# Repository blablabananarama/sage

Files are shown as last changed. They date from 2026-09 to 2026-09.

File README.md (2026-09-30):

# Bayleaf: ultra-low-profile wireless split keyboard (reproduction)

This is an open, buildable re-creation of Sebastian Graz's [Bayleaf](https://www.graz.io/articles/bayleaf-wireless-keyboard/): a 60-key (2 × 5×6) ortholinear split keyboard. It uses Kailh PG1316S laptop-style switches, runs ZMK on nice!nano controllers, and sits in a CNC-machined aluminium case 5 mm thick.

> **Provenance.** The original Bayleaf is a one-off prototype and is **not open source**. None of its files are used here. This repository is an independent design built to the published specs (139 × 93 mm per half, 5 mm thick, ~180 g, PG1316S, nice!nano/ZMK, CNC aluminium enclosure, MJF keycaps). Everything else was designed from scratch: board layout, pin mapping, case geometry, keymap and part choices. The PG1316S land pattern comes from Kailh's datasheet (CPG1316S01D02).

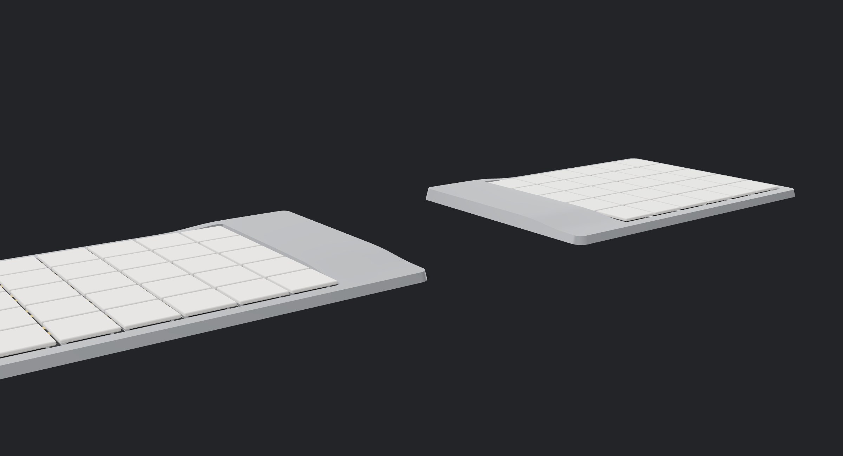
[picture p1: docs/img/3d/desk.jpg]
Bayleaf reproduction on a desk mat


| | |
|---|---|
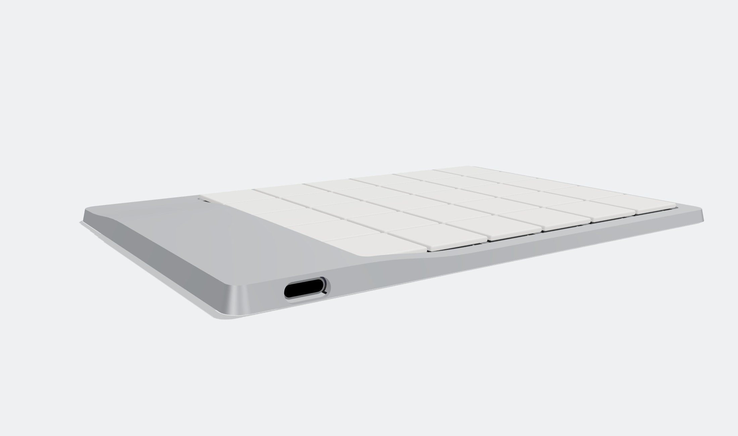
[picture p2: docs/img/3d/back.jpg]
back: USB-C in the S-bend below the plateau
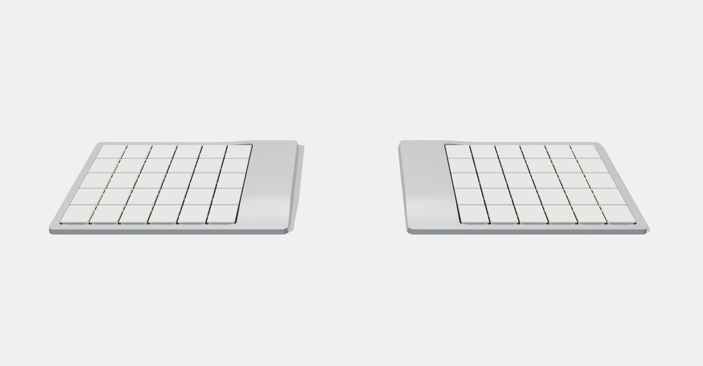
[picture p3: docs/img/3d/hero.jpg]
both halves
|  |  |
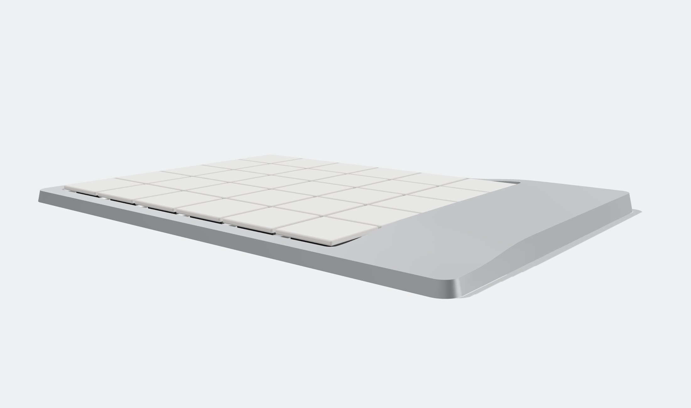
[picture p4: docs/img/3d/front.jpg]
front: the rim rising into the plateau
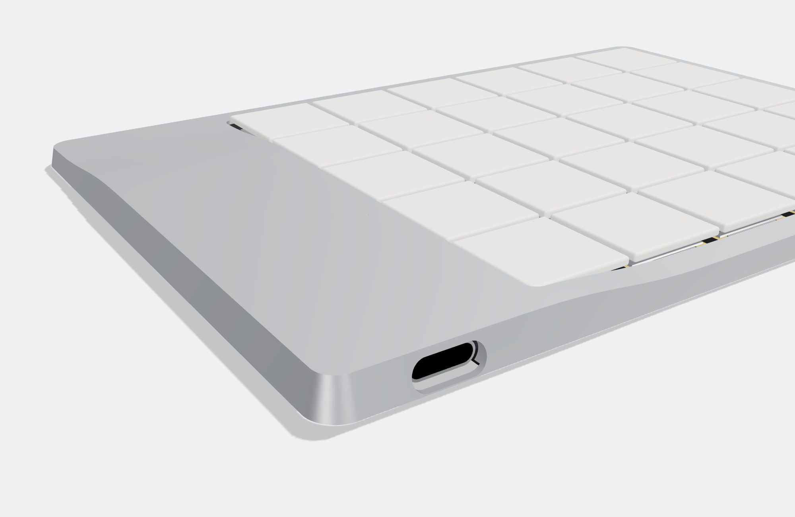
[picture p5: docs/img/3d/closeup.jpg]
controller corner: plateau and bends
|  |  |
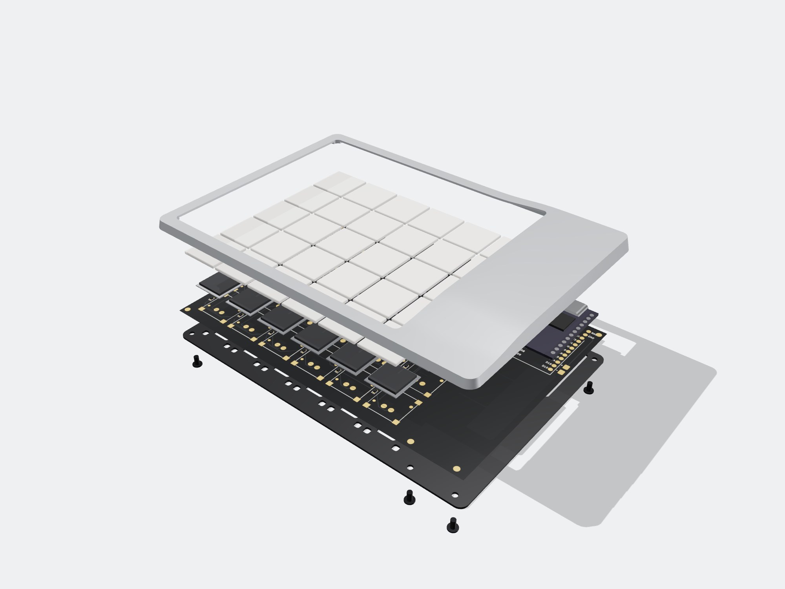
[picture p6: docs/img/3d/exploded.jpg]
exploded: shell, keycaps, switches, PCB, bottom plate, screws
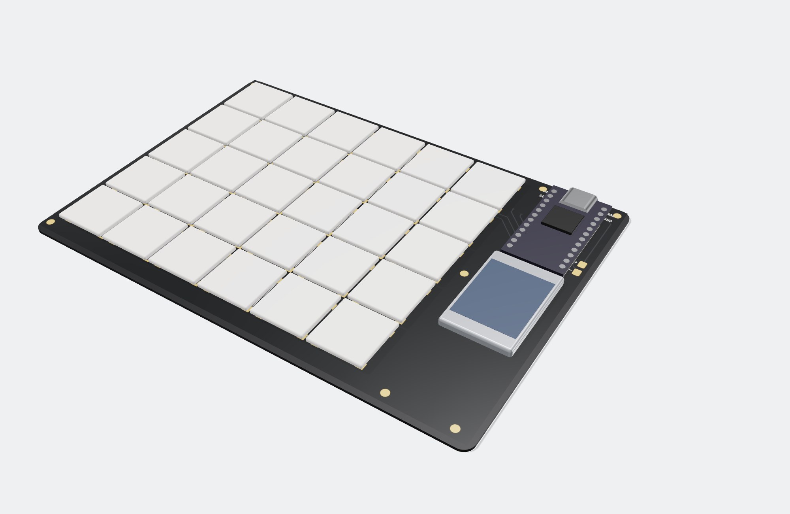
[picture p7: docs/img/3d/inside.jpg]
inside: PCB with the nice!nano, battery and switches
|  |  |
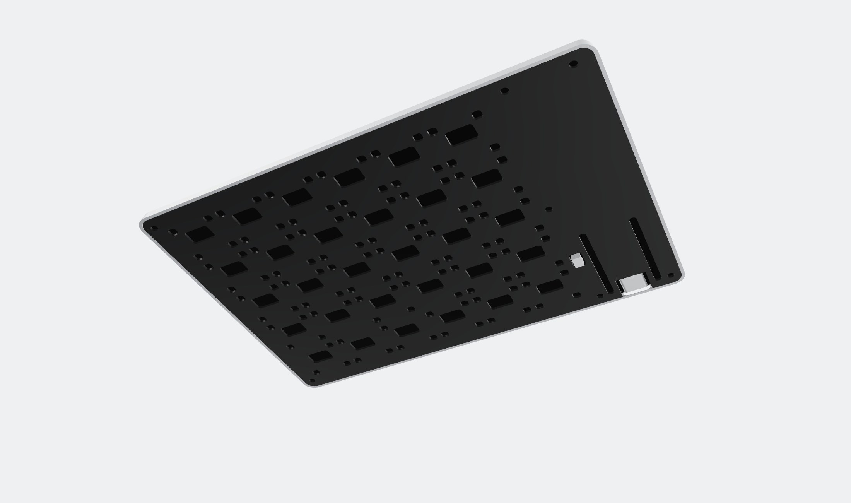
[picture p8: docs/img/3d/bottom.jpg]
underside: black FR4 bottom plate with its windows and the reset button
|  | |
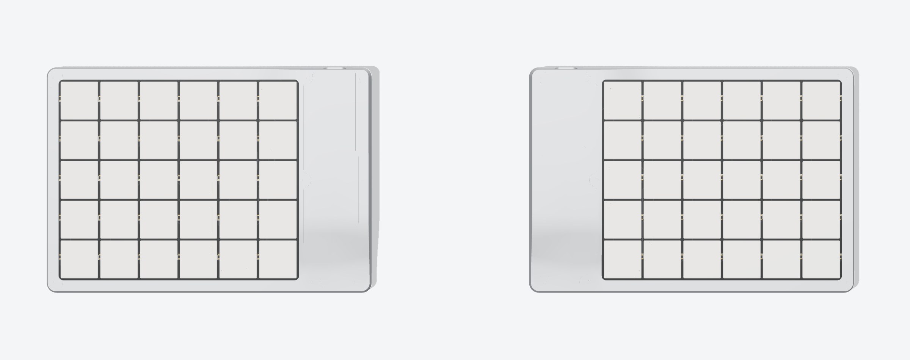
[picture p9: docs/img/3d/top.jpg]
top view
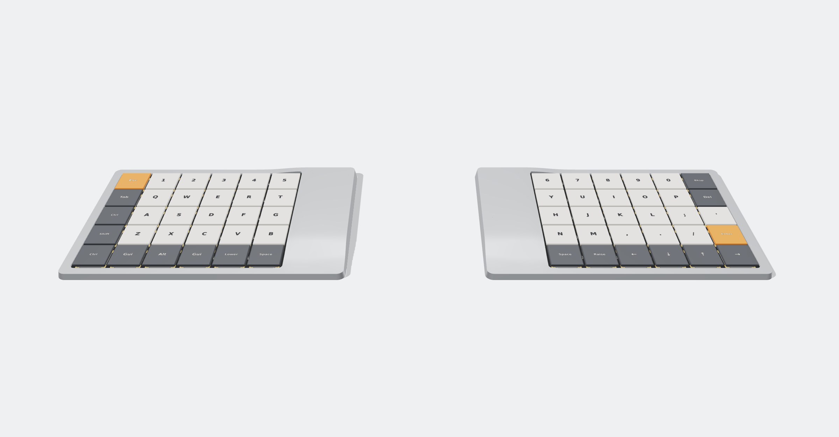
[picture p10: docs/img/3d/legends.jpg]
with the default keymap as legends
|  |  |

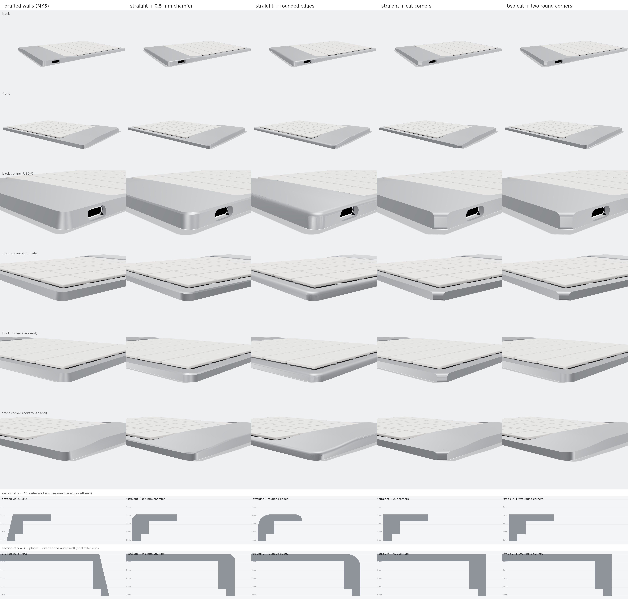
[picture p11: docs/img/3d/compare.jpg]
case variants side by side: drafted walls, straight + chamfer, straight + rounded edges, straight + cut corners


**[Interactive case viewer](https://claude.ai/artifact/CuZ9wQ9LTKb2B2hHYhkEA2)**: rotate the five case versions, switch between them and try finishes (source: `docs/viewer/index.html`).

*Renders are generated from the actual STEP files and the routed PCB artwork (`docs/render3d/render.sh`). The case follows the original's MK5 drawing for the plan view and, for the top surface, the shape drawn in the [case sketchpad](https://claude.ai/artifact/11zAxZXfv3bXQXGKN8ovCU) ([data](docs/case-sketchpad-shape.json)): a one-piece silver shell with two flat levels, a 3.2 mm rim around the keys and a 5.0 mm plateau over the controller, joined by soft S-bends, plus a screwed-on black FR4 bottom plate.*

| | Original Bayleaf (published) | This reproduction |
|---|---|---|
| Layout | 60 % ortholinear split | 2 × 5 rows × 6 columns, 17 × 17 mm pitch |
| Size per half | 139 × 93 mm; "tallest part is only 5 mm" | 139.4 × 96.8 mm base. 3.2 mm rim around the keys; 5.0 mm plateau over the controller |
| Weight | 180 g | ~165 g estimated (15 g aluminium shell + 17 g FR4 plate per half) |
| Switches | Kailh PG1316S | Kailh PG1316S, soldered from below with an iron: contacts through castellated half-holes, frame anchors through plated holes (a hotplate is optional) |
| Keycaps | custom MJF prints | stock Kailh PG1316S 1U caps (16 × 16 mm) |
| Controller | nice!nano, ZMK | nice!nano v2 soldered flush, ZMK (BLE split) |
| Battery | "over a month" | 302030 LiPo (~120–150 mAh) per half, deep sleep after 15 min |
| Case | CNC aluminium, raised over the controller | One-piece CNC 6061 shell (key window, roofed controller bay, 7 tapped M2 posts) + 0.8 mm FR4 bottom plate (a copper-free PCB, so the radio gets out) ([notes](docs/case-drawing.md)) |

## What's in here

```
hardware/pcb/generate_pcb.py      the whole PCB as code: placement, nets, outline -> Freerouting -> DRC -> fab files;
                                  also the FR4 bottom plates
hardware/pcb/bayleaf-{left,right}.kicad_pcb   routed KiCad 7 boards (open in KiCad to inspect or edit)
hardware/pcb/lib/bayleaf.pretty/  footprints: PG1316S (castellated, hand-solderable), nice!nano (flush), battery pads
hardware/pcb/fab/{left,right}/    gerbers+drill zip, JLCPCB BOM/CPL, 3D STEP of the board, DRC report
hardware/pcb/fab/plate-{left,right}/  gerbers+drill zip of the FR4 bottom plates
hardware/case/case.py             parametric shell (drafted or straight + chamfer) (CadQuery); out/ has STEP + STL (plate too, for reference)
firmware/                         ZMK shield "bayleaf" + keymap; built by .github/workflows/firmware.yml
docs/BOM.csv                      full bill of materials with prices
docs/ordering.md                  exact fab settings (PCB, PCBA, CNC, parts)
docs/shopping-list.md             every part to buy, with shop links
docs/assembly.md                  step-by-step build guide
docs/schematic.md                 circuit / pin map
docs/case-drawing.md              case dimensions, tapped holes, screws
```

| Left PCB | Right PCB |
|---|---|
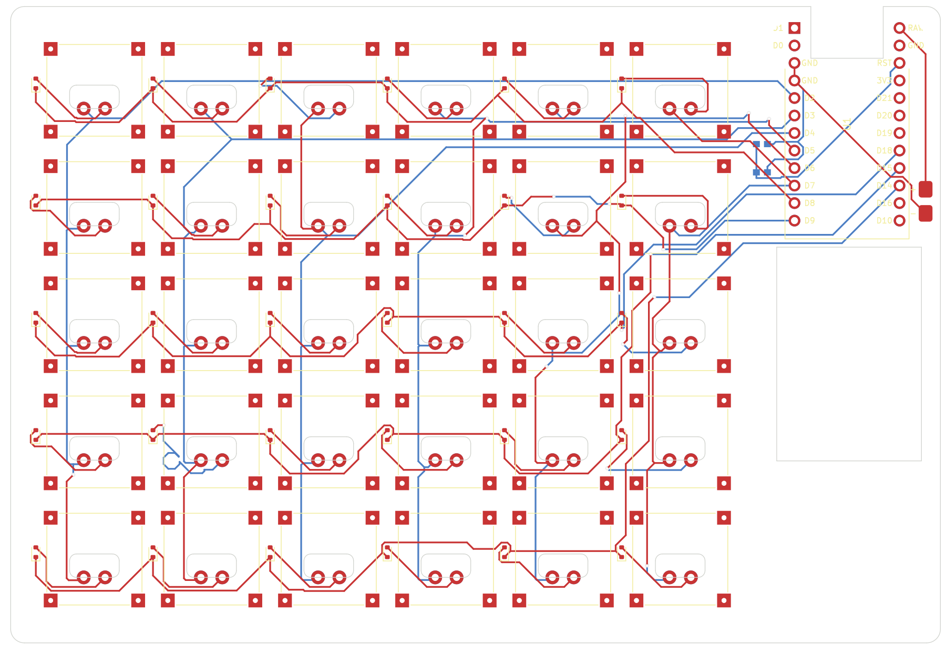
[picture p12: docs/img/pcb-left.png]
left pcb
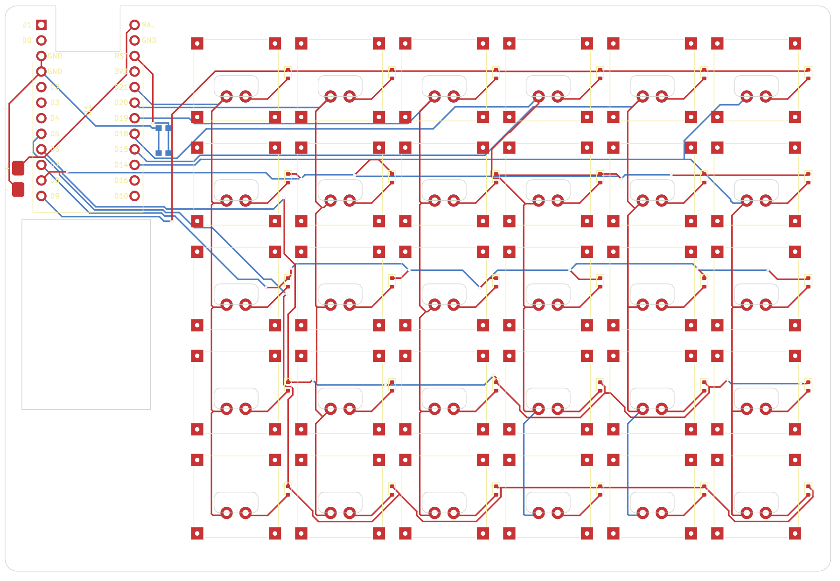
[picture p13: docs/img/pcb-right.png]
right pcb
|  |  |

## How much does one cost?

These are estimates from September 2026 for a single keyboard, including spares and shipping. The details are in [`docs/BOM.csv`](docs/BOM.csv).

| | USD |
|---|---:|
| PCBs (2 designs × 5 pcs, 0.8 mm, ENIG, castellated holes) | 60 |
| FR4 bottom plates (2 designs × 5 pcs, no copper) | 16 |
| 64 × Kailh PG1316S switches | 64 |
| 60 × PG1316S keycaps | 27 |
| 2 × nice!nano v2 | 50 |
| 2 × LiPo 302030 | 8 |
| Diodes, reset buttons | 2 |
| Foam tape, Kapton tape, bumpons, M2 screws | 17 |
| Shipping (rough) | 35 |
| 2 × CNC aluminium shell (6061, anodised) | 170 |
| **Electronics only** (PCBs, switches, diodes, controllers, batteries, reset buttons) | **≈ $184** |
| **Total with aluminium case** | **≈ $449** |
| **Total with printed nylon case instead** | **≈ $309** |

Optional extras: JLCPCB assembly of the 60 diodes (≈ $35), SMT stencils (≈ $14), and low-temp paste; a small hotplate is optional (≈ $30–120).

Most of the extra units are leftovers you can't avoid: 3 spare PCBs per side at the 5-piece minimum, spare switches, and so on.

## Build it

1. **Order**: follow [docs/ordering.md](docs/ordering.md). Upload the gerber zips, optionally the JLC BOM/CPL, and the case STEP files. Buy switches, caps, 2 nice!nanos and 2 cells.
2. **Firmware**: GitHub Actions builds `bayleaf_left`, `bayleaf_right` and `settings_reset` UF2s on every push. See [firmware/README.md](firmware/README.md).
3. **Assemble**: follow [docs/assembly.md](docs/assembly.md). The rough order is diodes → switches (iron from below: frame anchors, then contacts) → reset button (underside) → nice!nano flush → battery → PCB into the shell → bottom plate + 7 screws.

## Regenerating the design

The committed outputs are all you need to order. To change something (pitch, board size, pin map, case wall), edit the constants at the top of `generate_pcb.py` or `case.py` and run:

```sh
make pcb      # KiCad 7 python (pcbnew) + Freerouting 2.x jar (FREEROUTING_JAR=...)
make case     # CadQuery (shell; imports the FR4 plate for the renders)
make render   # README renders (docs/render3d)
```

The PCB script autoroutes with Freerouting and re-runs until nothing is unrouted. It writes a DRC report next to the gerbers. The committed boards have **0 unconnected pads and 0 electrical DRC errors**; the report only lists cosmetic silkscreen and library-path warnings. The bottom plates are generated in the same run. Freerouting isn't deterministic, so each regeneration produces different (equally valid) traces.

## Status and caveats

* **Not yet built.** The design passes DRC and the case was checked against the board in CAD, but no physical prototype exists yet. Order one set of PCBs before ordering in quantity.
* **Hand-solderable switches.** The PG1316S footprint uses the trick from Mike Holscher's working [mikecinq](https://github.com/mikeholscher/zmk-config-mikecinq): a window in the board under each switch, with the two contacts on plated half-holes at its edge, soldered from below with an iron. On top of that, each of the four frame-anchor pads has a plated hole with a bottom pad, so the anchors can be soldered from below too and no hotplate is needed. The anchor holes are **my addition and untested**: solder one switch first and check it holds before doing the rest. The hotplate route still works on the same board. The footprint is drawn independently from the Kailh land pattern, using his proven contact positions. Order the PCB with *castellated holes*, and print it 1:1 to check against a real switch first.
* The nice!nano is soldered flush, without sockets, to reach 5 mm. Flash and test it **before** soldering it down.
* The LCSC part numbers in the BOM are well-known parts, but check stock before ordering.
* **Case vs. the original.** The plan view comes from the MK5 drawing and the top surface from the sketchpad shape (3.2 / 5.0 mm levels, a square-cornered plateau at x ≥ 96.5, y ≤ 76 mm, 16.5 mm S-bends). The overall depth (4.2 mm border all round) and the keycap height (~4.4 mm) are my estimates. [docs/case-drawing.md](docs/case-drawing.md) marks which numbers come from where.
  * The plateau only covers the back 76 mm of the controller strip, so the PCB is laid out for it: the nice!nano's USB-C faces the **back** wall, the reset button (KMR2) sits beside it, and the cell is a **302030** in front of it (a 302040 would run into the bend).
  * The two posts beside the USB port are moved outward, so they don't land on the nice!nano's pins.
  * Threads are 2 mm deep under the plateau and 1.1 mm under the rim (M2×2 screws there); the drawing's 3 mm ones don't fit under 5 mm.
  * **No power switch.** The cell is wired straight to the nice!nano; ZMK's deep sleep (after 15 min idle, a key press wakes it) keeps the drain to a few µA. To store it for months, unsolder a battery lead.
  * The USB-C opening is a stadium around the receptacle (9.7 × 3.9 mm). The receptacle sits 1.5–2 mm behind the outer wall, so the cable's plug overmold has to fit that opening: slim-overmold cables and magnetic-tip adapters work, bulky plugs won't seat.
  * **Five wall styles** are generated ([comparison from four sides, with cross-sections](docs/img/3d/compare.jpg)). All use the same bottom plate and PCB:
  * default: the drafted walls of the MK5 drawing
  * `bayleaf-shell-*-chamfer`: straight walls with a 0.5 mm × 45° chamfer along the top edge
  * `bayleaf-shell-*-round`: straight walls with the top edge rounded over (R1.5) and a softened key-window edge (R0.8)
  * `bayleaf-shell-*-corner`: straight walls with sharp edges; each outer corner is cut at 45° (2.5 mm legs), and only that corner face gets a R1.5 top and R0.8 bottom round
  * `bayleaf-shell-*-corner2`: the same cut corners only at the back corner by the USB-C and the diagonally opposite front corner; the other two corners keep the R4.2 plan radius ([close comparison](docs/img/3d/compare-corners.jpg))
* **Radio.** The nice!nano sits under the aluminium roof, so the bottom plate is FR4 without any copper: the 2.4 GHz signal leaves downward and through the key window instead of being boxed in. The LiPo sits right at the antenna end of the nice!nano, which costs some range too. The firmware uses +8 dBm TX power. Test range before relying on it; a printed shell is the fallback.
* **Reset button** is on the PCB's underside, in a window of the bottom plate (it stands ~1.1 mm proud of the plate, inside the 1.5 mm feet). JLC's economic assembly is top-side only, so it's hand-soldered.

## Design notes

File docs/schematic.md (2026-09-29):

# Bayleaf schematic

The PCBs are generated straight from `hardware/pcb/generate_pcb.py`, with no separate KiCad schematic, so this page is the schematic. Both halves have the same circuit. The right PCB is a mirrored layout; its matrix uses different controller pins (table below).

## Key matrix (per half: 5 rows × 6 columns, diodes `col2row`)

```
 COLn ──┬──────────────┬─── … (one column wire per physical column)
        │              │
      SWx(1)         SWy(1)        SW = Kailh PG1316S, pad 1 = column side
      SWx(2)         SWy(2)
        │              │
        ▼ D (1N4148WT) ▼            anode = pad 2 (switch side), cathode = pad 1
        │              │
 ROWm ──┴──────────────┴─── … (one row wire per row)
```

| Net | Left half: pin (GPIO, `&pro_micro`) | Right half: pin (GPIO, `&pro_micro`) |
|---|---|---|
| COL0 | D2 (P0.17, 2) | D21 (P0.31, 21) |
| COL1 | D3 (P0.20, 3) | D20 (P0.29, 20) |
| COL2 | D4 (P0.22, 4) | D19 (P0.02, 19) |
| COL3 | D5 (P0.24, 5) | D18 (P1.15, 18) |
| COL4 | D6 (P1.00, 6) | D15 (P1.13, 15) |
| COL5 | D7 (P0.11, 7) | D14 (P1.11, 14) |
| ROW0 (back row) | D8 (P1.04, 8) | D9 (P1.06, 9) |
| ROW1 | D9 (P1.06, 9) | D8 (P1.04, 8) |
| ROW2 | D18 (P1.15, 18) | D7 (P0.11, 7) |
| ROW3 | D15 (P1.13, 15) | D6 (P1.00, 6) |
| ROW4 (front row) | D14 (P1.11, 14) | D5 (P0.24, 5) |

The nice!nano sits with its USB-C facing the back edge (the case's USB-C opening is in the back wall). Each half uses the pin column that faces its keys for the columns, and continues the rows on the nearer pins. The NFC pins (D10/D16) and the serial pins (D0/D1) are left unused.

On each half, columns are numbered left → right, so the right half's COL0 is its innermost column. The pins are set per half in `bayleaf_left.overlay` / `bayleaf_right.overlay`, and the right half adds `col-offset = <6>`.

## Power and misc

```
 LiPo + ── BT1.1 ── nice!nano RAW/B+   (no power switch; ZMK deep sleep after 15 min idle)
 LiPo − ── BT1.2 ── GND ── nice!nano GND (2 pins wired; the third, B−, is tied internally)

 nice!nano RST ── SW31 (KMR2 tact switch, bottom side) ── GND   double-tap → UF2 bootloader
```

The nice!nano handles charging over its own USB-C port, battery protection and 3.3 V regulation. There is no other active circuitry on the board.

## Mechanical notes that affect the circuit

* The nice!nano is soldered flush on the top side. Traces run under it on both layers, protected by soldermask; put a piece of Kapton on the PCB there before soldering it down.
* The nice!nano's USB-C faces the back edge. The mid-mount receptacle hangs about 1.1 mm below the nice!nano, into a notch in the PCB's back edge; the bottom plate has a notch below it.
* The 302030 cell sits in a window in the PCB in front of the controller, on the bottom plate.
* The seven aluminium bosses of the case press on the top of the PCB. Keep-out zones keep top copper and vias away from them, and the M2 screws pass through 2.2 mm non-plated holes.
* The PG1316S frame pads (`MP`) are not connected to anything. They are solder anchors only; each has a 0.7 mm plated hole with a 1.4 mm bottom pad, so it can be soldered from below with an iron.
* The PG1316S contacts (pads 1/2) are **castellated half-holes** on the front edge of a window under each switch, so they're soldered from below with an iron; the autorouter treats the windows as keep-outs.
* The reset button SW31 is the only part on the bottom side. It sits in a window of the FR4 bottom plate.

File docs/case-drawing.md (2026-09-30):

# Case: manufacturing notes

The case comes from two sources:
- **Plan view:** the original's drawing **bayleaf-case-MK5_L**. Values from it are marked **[D]**.
- **Top surface:** the shape sent through the [Bayleaf Case Sketchpad](https://claude.ai/artifact/11zAxZXfv3bXQXGKN8ovCU), saved as [`case-sketchpad-shape.json`](case-sketchpad-shape.json). Values from it are marked **[S]**.

Per half there is one CNC part, the 6061-T6 top shell (bead-blasted and anodised), and a bottom plate made as a copper-free 0.8 mm FR4 PCB. The STEP files are in `hardware/case/out/`, the plate gerbers in `hardware/pcb/fab/plate-{left,right}/`, and the right half is the mirror image.

| Part | File | Size | Weight |
|---|---|---|---|
| Top shell (one piece, rim + controller roof) | `bayleaf-shell-{left,right}.step` | 139.4 × 96.8 × 5.0 mm | ≈ 15 g |
| … or the straight-wall variant | `bayleaf-shell-{left,right}-chamfer.step` | 139.4 × 96.8 × 5.0 mm | ≈ 17 g |
| Bottom plate (FR4) | gerbers in `hardware/pcb/fab/plate-{left,right}/`; `bayleaf-plate-*.step` for reference | 137.3 × 94.7 × 0.8 mm | ≈ 17 g |

A finished half weighs about 82 g with the electronics, so about 165 g for the pair. The original is 180 g.

## Top surface: two flat levels joined by soft S-bends [S]

```
           x = 0                    96.5        137
   y = 0   ┌──────────────────────────┬───────────┐  back (USB-C)
           │                          ╎  HIGH     │
           │   LOW  3.2 mm            ╎  5.0 mm   │
           │   (rim around the keys)  ╎  plateau  │
   y = 76  │                  ╌ ╌ ╌ ╌ ┘           │
           │                                      │
  y = 94.4 └──────────────────────────────────────┘  front (typist)
```

* **LOW = 3.2 mm:** the rim around the key window and the whole front strip, about level with the keycap underside.
* **HIGH = 5.0 mm:** a plateau over the controller, x ≥ 96.5 mm and y ≤ 76 mm. It has square corners (the sketch's rectangle, straightened as the note asked) and is the tallest point, slightly above the ~4.4 mm keycap tops.
* **S-bends:** both inner edges of the plateau blend into the rim over 16.5 mm (10–90 %). The blend is a Gaussian-blurred step, `top_z(x, y)` in `case.py`, so where the two bends meet at the plateau's inner corner the surface stays smooth. On the back face this gives the S-curve beside the USB-C, and the second S runs across the top toward the front.
* The roof over the controller is part of the shell, continuous with the rim. There is **no separate lid**.

## Heights inside

```
5.0 mm  plateau top: the tallest point [S]
4.2 mm  roof underside over the controller (0.8 mm skin)
~4.4 mm keycap tops (PG1316S + stock cap on a 0.8 mm PCB)
~4.0 mm top of the nice!nano (only ~2.4 mm of its 3.2 mm sits above the PCB; the USB-C shell hangs into a PCB notch)
3.8 mm  top of the 3.0 mm LiPo (roof underside above it ≥ 4.0 mm)
3.2 mm  rim [S]; 2.4 mm underside
1.6 mm  PCB top
0.8 mm  bottom plate top
```

## Top shell

* **Top outline:** 137 mm wide **[D]**. The walls are drafted, so the base is 1.19 mm larger per side **[D]**. The depth is assumed to be 86 + 2 × 4.2 = 94.4 mm.
* **Key window:** 103 × 86 mm **[D]**, 4.2 mm from the edge **[D]**, with R2 inside corners **[S]**.
* **Skin:** 0.8 mm, following the top surface (rim and controller roof).
* **Divider:** 2 mm **[D]**. It stops 1.2 mm above the PCB so the SMD parts pass underneath.
* **Inside corners:** every vertical inside corner of the underside pocket (where the posts and the divider meet the walls and each other) is rounded to R1.65 mm, and gaps narrower than 3.3 mm (e.g. behind the two back posts) are left solid. So the pocket can be cut with a Ø3.3 mm end mill; SendCutSend's minimum is R1/16" = 1.59 mm. `MILL_R` in `case.py`.
* **Controller bay:** 27 mm **[D]**, closed on top by the shell's roof.
* **Bottom plate seat:** a rabbet 1.0 mm wide × 0.8 mm deep, leaving a 1 mm wall at the base **[D]**.
* **USB-C:** a stadium-shaped (obround) opening in the **back** wall, 9.7 × 3.9 mm with full-round ends, concentric with the 8.94 × 3.26 mm receptacle (centre z = 2.1 mm, x = 122.4 mm). Its lower curve dips 0.65 mm into the bottom plate's edge, which carries the same cut, so the outline reads as one clean stadium. There is no power-switch slot: the board has no power switch.

### Posts: M2×0.4 6H, blind from below, Ø2.4 × 90° countersink [D]

| Qty | Position (x, y from the back-left corner of the top outline) | Post | Thread | Note |
|---|---|---|---|---|
| 1 | (2.9, 3.5) | Ø6 | **1.1 mm** | back key-frame corner **[D]**, under the 3.2 mm rim |
| 1 | (2.9, 90.9) | Ø6 | **1.1 mm** | front key-frame corner **[D]**, under the rim |
| 2 | (111.2, 3.5), (133.95, 3.5) | Ø4 | 2 mm | back of the bay, flanking the USB-C. **Moved:** the drawing's pair is 19.039 mm apart, which would sit on the nice!nano's pins. |
| 1 | (109.5, 47.2) | Ø6 | 2 mm | middle of the divider **[D]** |
| 2 | (113.68, 90.9), (131.72, 90.9), 18.037 ±0.1 apart | Ø6 | **1.1 mm** | front of the bay **[D]**, under the rim |

The posts come down onto the PCB. The drawing's 3 mm-deep threads don't fit under a 5 mm keyboard, so `case.py` sizes each thread to leave 0.5 mm of material above it: 2 mm under the plateau, 1.1 mm under the rim. The STEP models them at the Ø1.6 mm tap-drill size; give the shop the thread callout.

## Wall variants

`case.py` writes five shells from the same top surface. They fit the same PCB, bottom plate and screws. See the [side-by-side comparison, with cross-sections](img/3d/compare.jpg).

| | Default (`bayleaf-shell-*`) | Chamfer (`…-chamfer`) | Round (`…-round`) | Cut corners (`…-corner`) |
|---|---|---|---|---|
| Outer walls | drafted, 1.19 mm per side **[D]** (137 × 94.4 at the top, 139.4 × 96.8 at the base) | vertical, 139.4 × 96.8 all the way up, R4.19 plan corners | same as chamfer | vertical, 139.4 × 96.8, plan corners cut at 45° with 2.5 mm legs (3.5 mm face) (`CORNER_CUT`) |
| Outer top edge | sharp | 0.5 mm × 45° chamfer (`CHAMFER`) | quarter-round R1.5 (`ROUND_OUT`) | sharp, except R1.5 along the corner faces (`CORNER_RT`) |
| Outer bottom edge | sharp | sharp | sharp | sharp, except R0.8 along the corner faces (`CORNER_RB`) |
| Key-window edge | sharp, R2 plan corners | sharp, R2 plan corners | quarter-round R0.8 (`ROUND_WIN`) | sharp, R2 plan corners |
| Weight | ≈ 15 g | ≈ 17 g | ≈ 16 g | ≈ 17 g |

`…-corner2` is the cut-corners version with only two cut corners: the back corner by the USB-C and the diagonally opposite front corner (at the key end). The other two corners keep the straight versions' R4.19 plan radius with sharp edges ([close comparison](img/3d/compare-corners.jpg)).

The cut-corners version is modelled the way you'd machine it. Each corner is cut at 45°, then only the new face's top and bottom edges are filleted; the vertical edges beside it stay sharp (`corner_cutter()`). At 2.5 mm the cut stays clear of the corner screw posts, the PCB and the bottom plate. A larger cut, up to about 6 mm (the nice!nano limits it), would need the corner posts moved and the PCB re-routed.

The chamfer and the rounds are cut as a second height field (`chamfer_field()` / `round_field()`): the top surface, lowered by the edge profile as a function of the distance in from the outline or the key window. So the edge keeps its profile across the S-bends and runs around the plan-view corners. OCC's own chamfer and fillet can't handle the blended top surface. For the round variant, the height field is sampled every 0.15 mm near the edges, which leaves facets of well under 0.1 mm.

## Bottom plate

* 0.8 mm FR4, made as a 2-layer PCB with **no copper**, black mask and silkscreen (generated by `generate_pcb.py`, `PlateBuilder`). Aluminium would close the Faraday cage around the nice!nano; FR4 lets the 2.4 GHz signal out downward. It also insulates, so no Kapton film is needed.
* It drops into the shell's rabbet and sits flush with the base. Seven Ø2.2 mm holes; the thin screw heads sit on its outside (0.5 mm, inside the 1.5 mm feet).
* Windows: one under each switch (8.0 × 5.2 mm, for the solder on the castellated contacts), four 2.6 × 2.6 mm ones per switch under the plated frame-anchor holes, two slots under the nice!nano pin rows, one for the reset button (3.9 × 6.1 mm; the KMR2 on the PCB's underside stands in it), and a 9.7 × 7.5 mm notch in the back edge under the USB-C receptacle, below the shell's stadium opening.

## Fasteners

The screws go up through the bottom plate and the PCB into the posts, so the posts clamp the board.

| Qty per half | Screw | Posts |
|---|---|---|
| 3 | M2 × 3, thin/wafer head (Ø4 × ≤ 0.5 mm head, "laptop screw") | two at the back of the bay, one in the divider |
| 4 | M2 × 2, thin/wafer head | the four under the 3.2 mm rim (1.1 mm threads) |

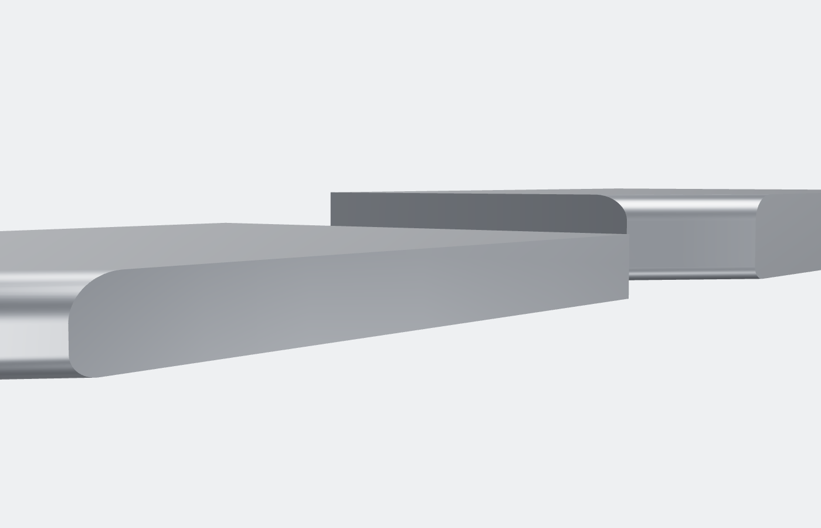
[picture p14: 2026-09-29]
docs/img/intent/corner-mockup-side.png

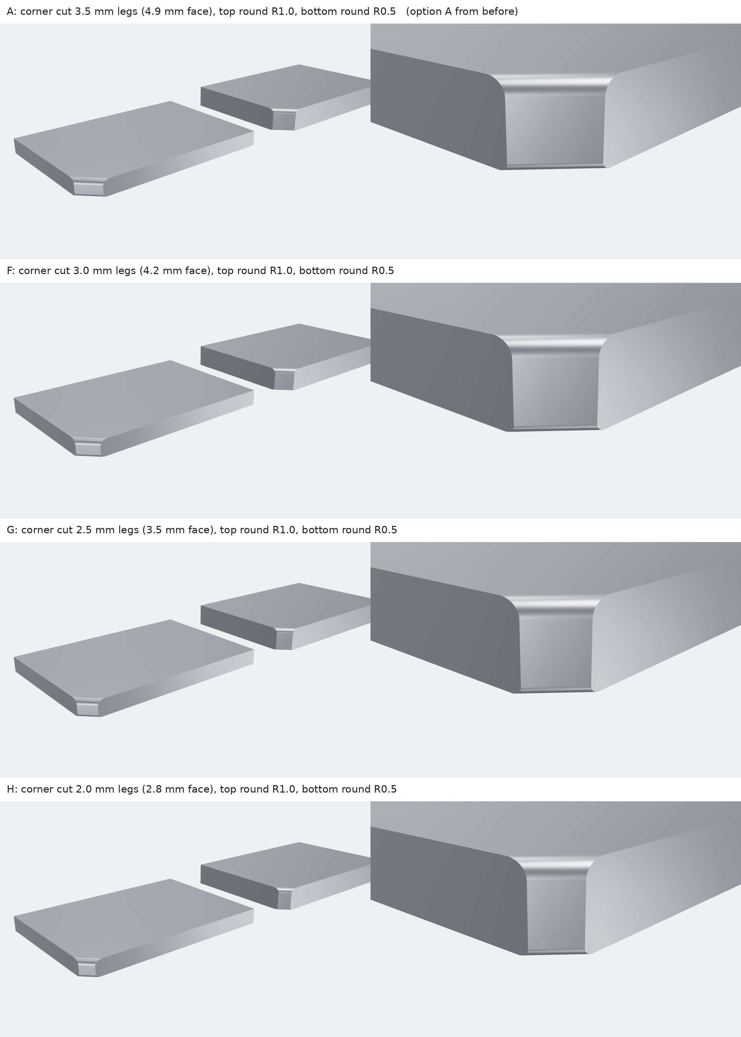
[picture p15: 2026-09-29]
docs/img/intent/corner-options-small.jpg

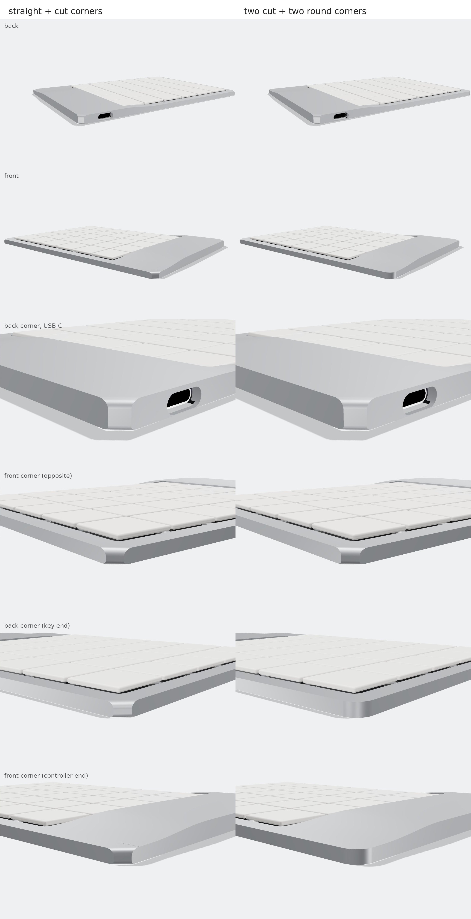
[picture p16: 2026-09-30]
docs/img/3d/compare-corners.jpg

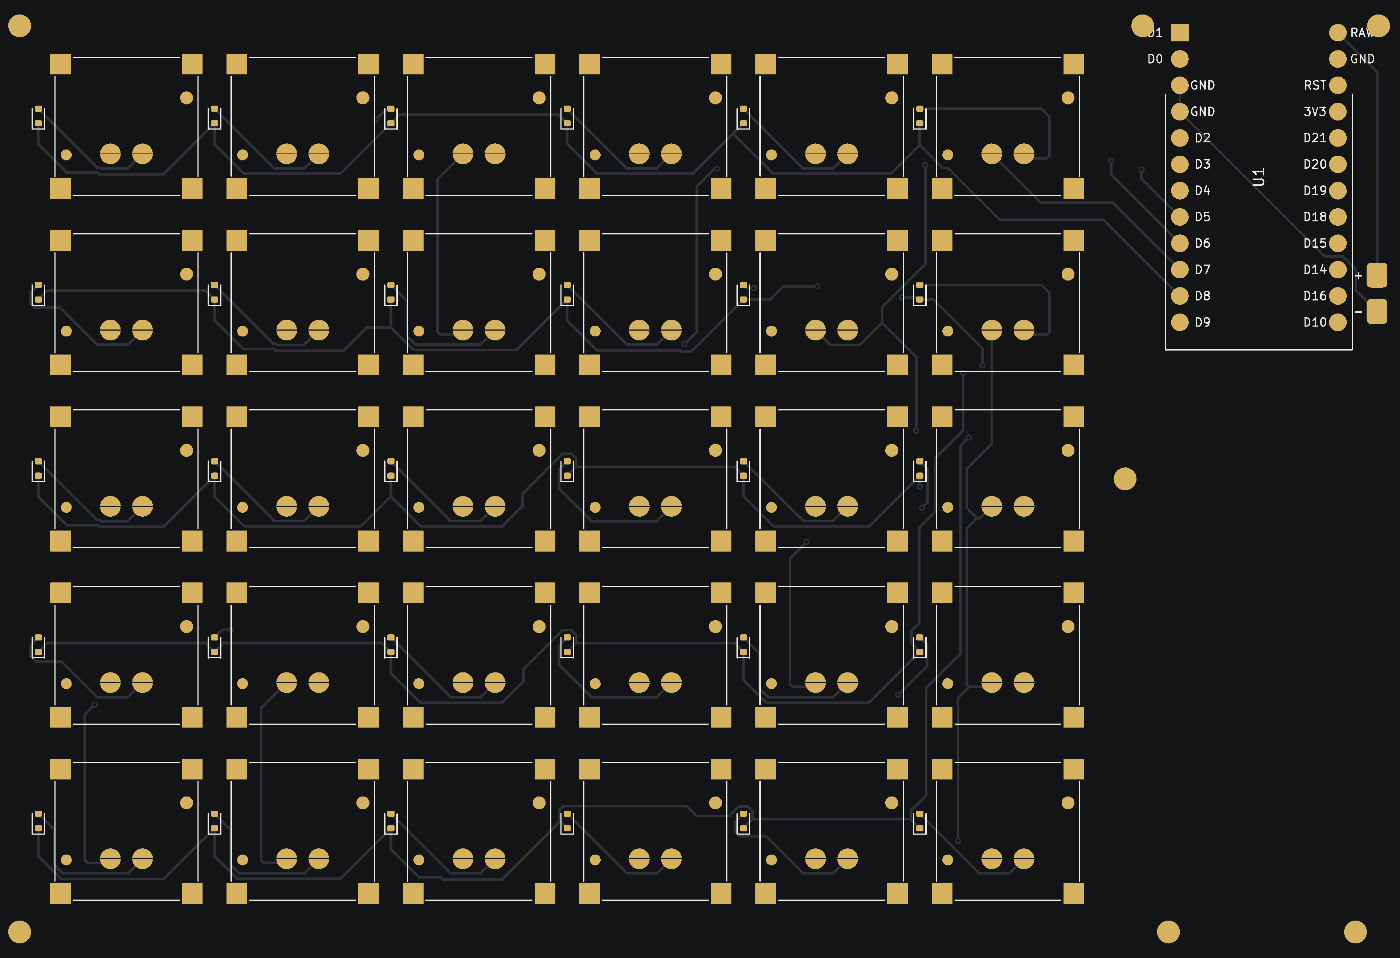
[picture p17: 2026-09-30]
docs/viewer/pcb-left-top.png

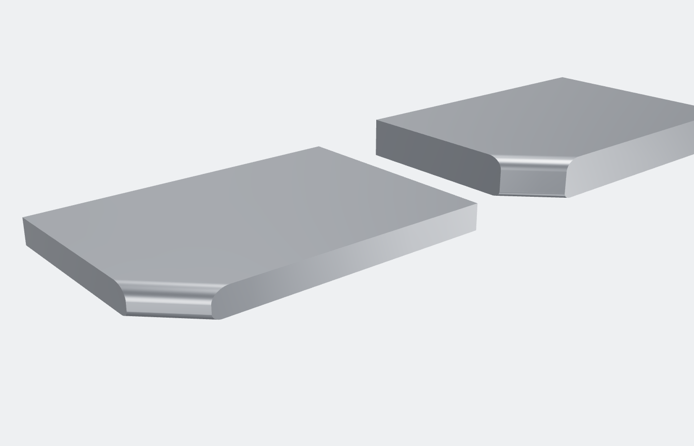
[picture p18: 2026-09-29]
docs/img/intent/corner-mockup-3q.png

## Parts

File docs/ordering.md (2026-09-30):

# Ordering the parts

Prices are estimates from September 2026 for a single build. See [`BOM.csv`](BOM.csv) for the per-line breakdown.

## 1. PCBs (JLCPCB, or any other fab)

Upload `hardware/pcb/fab/left/bayleaf-left-gerbers.zip` and `hardware/pcb/fab/right/bayleaf-right-gerbers.zip` as **two separate orders or two items in one cart**. The halves are mirror images, not the same board.

| Setting | Value |
|---|---|
| Layers | 2 |
| Dimensions | 134.9 × 92.3 mm (auto-detected) |
| PCB thickness | **0.8 mm** (1.0 mm also works; the case then sits 0.2 mm higher) |
| Surface finish | **ENIG** recommended (flat pads for the SMD switches); lead-free HASL works |
| **Castellated holes** | **Yes** (≈ $8 extra per design). The two switch contacts sit on plated half-holes at the edge of a window under each switch, so you can solder them from below with an iron. The fab may flag the 30 internal windows; they're intended |
| Min. hole / via | 0.3 mm drill / 0.6 mm pad, which is standard |
| Min. track / spacing | 0.25 mm / 0.25 mm, which is standard |
| Mark on PCB | "Remove mark" or "specify position". Otherwise the fab may print its order number between the keys |
| Stencil (optional) | Framework or frameless stencil from the `F.Paste` layer (frame anchors and diodes only) |

### Bottom plates (same order)

Upload `hardware/pcb/fab/plate-left/bayleaf-plate-left-gerbers.zip` and `…/plate-right/bayleaf-plate-right-gerbers.zip` as two more designs: 2 layers, **0.8 mm**, **black** solder mask, white silkscreen, any finish (there's no copper). They're the case floor: FR4 lets the Bluetooth signal out, where the old aluminium plate shielded the controller. Keep them copper-free; don't let the fab add a copper pour or "thieving".

### Optional: let JLCPCB place the small parts (PCBA)

Turn on *PCB Assembly → Economic, top side*. Then upload for each half:

* BOM: `hardware/pcb/fab/<side>/bayleaf-<side>-jlc-bom.csv`
* CPL: `hardware/pcb/fab/<side>/bayleaf-<side>-jlc-cpl.csv`

This places D1–D30 (1N4148WT, SOD-523: pick a stocked part in JLC's search) (the reset button SW31 is on the bottom side, which economic assembly doesn't cover; solder it by hand). **Check stock and the rotation preview** before paying. JLC's part library sometimes needs a 180° correction for small diodes. On the right PCB the diodes' cathode (pad 1, the band) must sit toward the **row** trace; in the 3D preview, check that the band points to the same side as the silkscreen band.

The switches (PG1316S) and the nice!nano are not placed by JLC. You solder them yourself (see [assembly.md](assembly.md)).

## 2. Keyboard parts

* **60 × Kailh PG1316S** plus a few spares. Pick the force you like; the lighter 25–35 gf versions are quieter. Sold as 5- or 10-packs by beekeeb, keycapsss, holykeebs and modulo.industries.
* **60 × PG1316S 1U keycaps** (16 × 16 mm) from the same shops.
* **2 × nice!nano v2**. Don't buy the "low-profile headers/sockets"; they aren't used.
* **2 × LiPo 302030** (3.0 × 20 × 30 mm, about 120–150 mAh) with a protection PCB and short leads. The PCB window under the controller roof takes a cell up to 3.0 × 21 × 31 mm; a thicker or longer cell reaches the S-bend where the roof drops.

## 3. Case (one-piece top shell)

The case follows the original's MK5 drawing for the plan view and the shape sent through the case sketchpad for the top surface: a 3.2 mm rim around the keys and a 5.0 mm plateau over the controller, joined by soft S-bends, all one piece. See [case-drawing.md](case-drawing.md) for all dimensions and what I changed.

* Upload `hardware/case/out/bayleaf-shell-{left,right}.step` (drafted walls) **or** `bayleaf-shell-{left,right}-chamfer.step` (straight walls, 0.5 mm chamfer on the top edge) **or** `bayleaf-shell-{left,right}-round.step` (straight walls, rounded top edges) **or** `bayleaf-shell-{left,right}-corner.step` (straight walls, 45° cut corners with rounded edges) **or** `bayleaf-shell-{left,right}-corner2.step` (the same, but only the USB-C corner and its opposite are cut; the other two are rounded); see [the comparison](img/3d/compare.jpg) to JLCCNC, PCBWay CNC, Xometry or similar. Order qty 1 of each. (The bottom plates are PCBs now, see above.)
  * Material: 6061-T6. Finish: bead blast + anodise. Silver/clear for the original's look.
  * Threads: 7 × M2×0.4, blind, cut up from the bottom into the posts: three 2 mm deep (back of the bay, divider) and four 1.1 mm deep (the posts under the rim). Add them in the shop's thread options or as a note; the STEP only contains the Ø1.6 mm tap drill.
  * Rough cost: $70–110 per half.
* **SendCutSend (CNC machining):** upload the shell STEP as is. Each file is one solid in mm, the threads aren't modelled, and the M2 holes are at the Ø1.6 mm tap-drill size. The inside corners are ≥ R1.65, which meets their R1/16" minimum.
  * Material 6061-T6; add anodising if you want it.
  * In their tapping options, pick M2×0.4 for the seven Ø1.6 holes on the underside. Four are only 1.1 mm deep (the posts under the rim), three are 2 mm deep.
  * Their page lists 1 × 1 × 1 in as the smallest part size, and the shell is 5 mm (0.2 in) thick. If the quote refuses it, send the same file to JLCCNC, PCBWay or Xometry.
* **Printed (budget) option:** the same STEP files (with their curved surfaces, so they print well) come out in MJF PA12 or SLS nylon for about $15–25 per half. Use self-tapping M2 screws.
* **Screws:** 6 × M2×3 and 8 × M2×2 with a thin (≤ 0.5 mm) wafer head, e.g. a laptop-screw assortment.

## 4. Consumables

Thin foam tape for the battery, Kapton tape (under the nice!nano), 8 small silicone bumpons, and low-temperature solder paste (Sn42Bi58, 138 °C). The low-temperature paste keeps the switch housings well below the datasheet's 260 °C limit.

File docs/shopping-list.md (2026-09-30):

# Shopping list

Everything to buy for one Bayleaf (both halves), with links. Quantities include a few spares. Prices are the estimates from [`BOM.csv`](BOM.csv) (Sept 2026). Links were checked when this list was written, but shops change; any equivalent part works unless the note says otherwise.

## Made to order from the repo files

| ✓ | What | Qty | Where | Files / settings |
|---|---|---|---|---|
| ☐ | Key PCB, left | 5 (min.) | [JLCPCB](https://jlcpcb.com/) | `hardware/pcb/fab/left/bayleaf-left-gerbers.zip` · 2 layers, **0.8 mm**, ENIG, **castellated holes: Yes**, remove mark |
| ☐ | Key PCB, right | 5 (min.) | [JLCPCB](https://jlcpcb.com/) | `hardware/pcb/fab/right/bayleaf-right-gerbers.zip` · same settings |
| ☐ | Bottom plate, left (FR4) | 5 (min.) | [JLCPCB](https://jlcpcb.com/) | `hardware/pcb/fab/plate-left/bayleaf-plate-left-gerbers.zip` · 2 layers, **0.8 mm**, black mask, no copper fill |
| ☐ | Bottom plate, right (FR4) | 5 (min.) | [JLCPCB](https://jlcpcb.com/) | `hardware/pcb/fab/plate-right/bayleaf-plate-right-gerbers.zip` · same settings |
| ☐ | Top shell, left + right | 1 + 1 | [JLCCNC instant quote](https://jlccnc.com/cnc-machining-quote) or [SendCutSend CNC](https://sendcutsend.com/services/cnc-machining/) | `hardware/case/out/bayleaf-shell-{left,right}.step` (drafted walls), `…-chamfer.step` (straight walls, chamfer), `…-round.step` (straight walls, rounded edges) `…-corner.step` (straight walls, cut corners) **or** `…-corner2.step` (two cut + two rounded corners). 6061-T6, bead blast + anodise, 7 × M2×0.4 threads (see [ordering.md](ordering.md)) |

Optional: a stencil for each key PCB in the same JLCPCB order (frame pads and diodes only).

## Electronics

| ✓ | What | Qty | Buy | Notes |
|---|---|---|---|---|
| ☐ | Kailh PG1316S switches | 64 (60 + 4 spare) | [beekeeb 40 gf](https://shop.beekeeb.com/products/pg1316s-40gf) / [25 gf](https://shop.beekeeb.com/products/pg1316s-25gf) (5-packs) · [holykeebs](https://holykeebs.com/products/kailh-pg1316s-butterfly-switch-10-pack) (10-packs) · [keycapsss 35 gf](https://keycapsss.com/Kailh-PG1316S-Ultra-Thin-Notebook-Switch/KC10231-35) · [modulo.industries](https://modulo.industries/product/pg1316s-switch/) | The mikecinq builder recommends 35 gf; 60 gf is heavy |
| ☐ | PG1316S keycaps, 1U | 60 | [keycapsss (black, 10×)](https://keycapsss.com/Kailh-PG1316S-Keycaps/KC10237-1U-BK) · [holykeebs](https://holykeebs.com/products/kailh-pg1316s-keycaps) · [modulo.industries](https://modulo.industries/product/pg1316s-keycap/) | 16 × 16 mm, stock Kailh caps |
| ☐ | nice!nano v2 | 2 | [Typeractive](https://typeractive.xyz/products/nice-nano) · [beekeeb](https://shop.beekeeb.com/products/nicenano) · [Little Keyboards](https://www.littlekeyboards.com/products/nice-nano) · [official store list](https://nicekeyboards.com/nice-nano/) | **Without** sockets/headers; it's soldered flush |
| ☐ | LiPo 302030, 3.7 V, with protection circuit | 2 | [KBT 302030 150 mAh (2-pack)](https://www.kbt18650battery.com/products/kbt-302030pl-3-7v-150mah-li-polymer-rechargeable-battery-2pack) · [LP302030 130 mAh](https://www.lipolbattery.com/Lithium-Ion-Polymer-Battery-LP302030.html) · [Amazon (JST lead)](https://www.amazon.com/Battery-Rechargeable-Lithium-Polymer-Connector/dp/B09F9V199L) | Max 3.0 × 21 × 31 mm. Must have the protection PCB. Cut off any connector; the leads are soldered to the pads |
| ☐ | Diode 1N4148WT, SOD-523 | 70 | [LCSC C511874](https://www.lcsc.com/product-detail/Switching-Diode_BORN-1N4148WT_C511874.html) · [LCSC C2961218](https://www.lcsc.com/product-detail/C2961218.html) | Skip if JLCPCB assembles the diodes |
| ☐ | Reset button C&K KMR211NGLFS (KMR2) | 2 (+ spares) | [DigiKey](https://www.digikey.com/en/products/detail/c-k/KMR211NG-LFS/2176482) | Any KMR2-footprint tact switch works; mounts on the PCB's underside |

## Mechanical and consumables

| ✓ | What | Qty | Buy | Notes |
|---|---|---|---|---|
| ☐ | M2 × 2 mm wafer-head screws | 8 | [Amazon (HH Fasteners, 50 pcs)](https://www.amazon.com/Machine-Screws-Laptop-Dia-5mm-Metric/dp/B01ILW3TS8) · [metricscrews.us](https://www.metricscrews.us/index.php?main_page=index&cPath=13_122_129_123) | The 4 posts under the rim per half (1.1 mm threads) |
| ☐ | M2 × 3 mm wafer-head screws | 6 | [Amazon (HH Fasteners, 50 pcs)](https://www.amazon.com/Machine-Screws-Laptop-Dia-5mm-Metric/dp/B01ILW3UV4) · [metricscrews.us](https://www.metricscrews.us/index.php?main_page=index&cPath=13_122_129_125) | The other 3 posts per half. These heads are Ø5 × 0.65 mm and sit on the outside of the plate, inside the feet |
| ☐ | Clear silicone bumpons | 8 | [Amazon (tiny bumpons)](https://www.amazon.com/Self-adhesive-Clear-Rubber-Feet-Bumpons/dp/B001JAW454) | 1.5–2.5 mm tall: taller than the reset button (1.1 mm below the plate) |
| ☐ | Kapton (polyimide) tape | 1 roll | [Amazon search](https://www.amazon.com/s?k=kapton+tape+10mm) | Under the nice!nano |
| ☐ | Thin double-sided foam tape | 1 roll | [Amazon search](https://www.amazon.com/s?k=thin+double+sided+foam+tape+1mm) | Holds the battery to the plate |
| ☐ | Low-temp solder paste Sn42Bi58 (Chip Quik TS391LT) | 1 syringe | [DigiKey](https://www.digikey.com/en/products/detail/chip-quik-inc/TS391LT/7802220) · [Amazon](https://www.amazon.com/Chip-Quik-TS391LT-Thermally-No-Clean/dp/B096BLQQNY) | Under the switch frame anchors (melted from below with the iron) and the diodes; no fridge needed |
| ☐ | Flux pen (e.g. Chip Quik CQ4LF) | 1 | [DigiKey search](https://www.digikey.com/en/products/result?keywords=CQ4LF) | For the contacts from below |
| ☐ | Thin solder wire (0.5 mm) | 1 | any | Contacts and nice!nano pins |

## Tools, if you don't have them

| ✓ | What | Buy | Notes |
|---|---|---|---|
| ☐ | Mini hotplate (optional) | [Miniware MHP30 (DFRobot)](https://www.dfrobot.com/product-2530.html) · [welectron (EU)](https://www.welectron.com/Miniware-MHP30-Hot-Plate-Preheater) · [SparkFun](https://www.sparkfun.com/mini-hot-plate-preheater-mhp30.html) | Only needed if the iron-only frame-anchor joints don't hold. 30 × 30 mm does one switch at a time |
| ☐ | Soldering iron with a fine and a small chisel tip (temperature-controlled), tweezers, flush cutters, multimeter, Phillips #00 driver | any | |

The nice!nano and its firmware: see [firmware/README.md](../firmware/README.md). Assembly: [assembly.md](assembly.md).

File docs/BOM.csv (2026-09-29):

Item | Qty (both halves) | Designators (per half) | Part | Specification / part number | Where to buy | Unit price USD (est. 2026-09) | Line total USD (est.) | Notes
1 | 2 designs x 5 pcs | - | PCB left + PCB right | 2-layer FR4, 0.8 mm, ENIG, any colour, castellated holes: Yes; gerbers in hardware/pcb/fab/{left,right}/bayleaf-*-gerbers.zip | JLCPCB / PCBWay | 30.00 | 60.00 | Price per design incl. ENIG and JLC's castellated-hole fee (~$8 + area); the half-holes let you solder the switch contacts from below with an iron
2 | 60 (+4 spare) | SW1-SW30 | Key switch | Kailh PG1316S (CPG1316S01D02), pick your weight (25/35/40/60 gf) | beekeeb, keycapsss, holykeebs, modulo.industries | 1.00 | 64.00 | Soldered from below with an iron: contacts through castellated half-holes, frame anchors through plated holes (hotplate optional; see docs/assembly.md)
3 | 60 | - | Keycap | Kailh PG1316S 1U keycap (16 x 16 mm) | keycapsss, holykeebs, modulo.industries | 0.45 | 27.00 | The original build used custom MJF-printed caps; stock Kailh caps fit the same switch
4 | 60 (+10 spare) | D1-D30 | Diode | 1N4148WT, SOD-523 (0.8 mm wide body; fits the 0.95 mm gap between keycaps) | LCSC / JLCPCB assembly | 0.02 | 1.40 | Search "1N4148WT" in the LCSC/JLC catalogue; any SOD-523 small-signal diode works
5 | 2 | U1 | Controller | nice!nano v2 (nRF52840, mid-mount USB-C, 3.2 mm thick) | nicekeyboards.com, typeractive.xyz, boardsource, mechboards | 25.00 | 50.00 | Soldered flush to the PCB, no headers/sockets
6 | 2 | BT1 | Battery | 3.7 V LiPo pouch cell 302030 (3.0 x 20 x 30 mm, ~120-150 mAh) with protection circuit | AliExpress / Adafruit-style LiPo shops | 4.00 | 8.00 | Sits on the bottom plate in the PCB window under the controller roof; max 3.0 x 21 x 31 mm (the roof underside is >= 4.0 mm there)
8 | 2 | SW31 | Reset button | C&K KMR211NGLFS (KMR2, 4.2 x 2.8 x 1.9 mm SMD tact switch) or a stocked KMR2-footprint clone | LCSC / JLCPCB assembly | 0.30 | 0.60 | On the PCB's bottom, in a window of the bottom plate; hand-soldered (JLC economic assembly is top-side only). Double-tap = bootloader
9 | 2 | - | Case: one-piece top shell | CNC 6061-T6, bead-blasted + anodised; hardware/case/out/bayleaf-shell-{left,right}[-chamfer].step; threads per docs/case-drawing.md | JLCCNC / PCBWay CNC / Xometry | 85.00 | 170.00 | Estimate per half $70-110. Budget: MJF/SLS nylon prints of the same file, ~$12-20 per half
9b | 2 designs x 5 pcs | - | Bottom plate (FR4) | 0.8 mm FR4 PCB without copper, black solder mask + silkscreen; gerbers in hardware/pcb/fab/plate-{left,right}/ | JLCPCB / PCBWay | 8.00 | 16.00 | Radio-transparent floor (the aluminium one shielded the nice!nano); windows for the switch solder, nice!nano pins, reset button and USB-C
10 | 1 roll | - | Foam tape | Thin double-sided foam tape for the battery | Amazon / hobby shops | 5.00 | 5.00
11 | 1 roll | - | Kapton tape | Polyimide tape | Amazon / hobby shops | 3.00 | 3.00 | Under the nice!nano; the FR4 bottom plate needs no insulating film
12 | 8 | - | Feet | Clear silicone bumpons, 6-8 mm dia, <= 1.5 mm tall | Amazon / hobby shops | 0.40 | 3.20
13 | 6 + 8 | - | Screws | M2 x 3 (6x) and M2 x 2 (8x), thin/wafer head (head <= 0.5 mm, dia 4 mm), e.g. laptop screw assortment | Amazon / AliExpress | 0.40 | 5.60 | 7 per half: M2 x 2 in the 4 posts under the 3.2 mm rim, M2 x 3 in the other 3; see docs/case-drawing.md
14 | 1 | - | Shipping | PCB order + switches/keycaps + controllers | - | 35.00 | 35.00 | Very rough; depends on country and shipping speed
 |  |  | ELECTRONICS ONLY (items 1-2, 4-6 and 8) |  |  |  | 184.00 | PCBs, switches, diodes, nice!nanos, cells, reset buttons; excl. keycaps, case, consumables, shipping
 |  |  | TOTAL (aluminium case) |  |  |  | 448.80 | Single build, parts incl. spares; excludes tools
 |  |  | TOTAL (printed nylon case) |  |  |  | 308.80 | Same, with ~$30 of MJF/SLS nylon shells instead of CNC aluminium
 |  |  | Optional: JLCPCB assembly of D1-D30 |  |  |  | 35.00 | ~$17 per design (setup + extended-part fee), saves soldering 60 small diodes
 |  |  | Optional: SMT stencils |  |  |  | 14.00 | One per design (F.Paste layer is in the gerber zip)
 |  |  | Tools if you have none | Fine-tip + small chisel-tip iron, optional mini hotplate (e.g. Miniware MHP30), low-temp solder paste Sn42Bi58, solder wire, flux, Phillips #00 driver |  |  | 60-120

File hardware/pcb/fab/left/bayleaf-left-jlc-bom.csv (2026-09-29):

Comment | Designator | Footprint | LCSC Part #
1N4148WT | D1,D2,D3,D4,D5,D6,D7,D8,D9,D10,D11,D12,D13,D14,D15,D16,D17,D18,D19,D20,D21,D22,D23,D24,D25,D26,D27,D28,D29,D30 | D_SOD-523

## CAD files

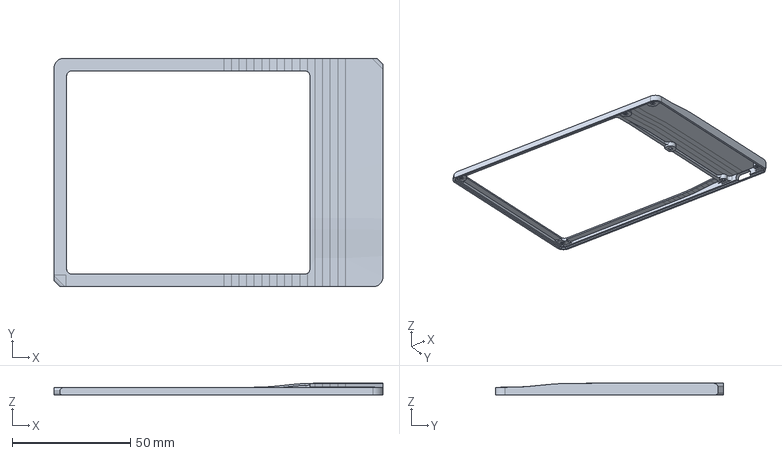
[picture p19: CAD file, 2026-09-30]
hardware/case/out/bayleaf-shell-left-corner2.step
139.4 x 96.8 x 5.00 mm

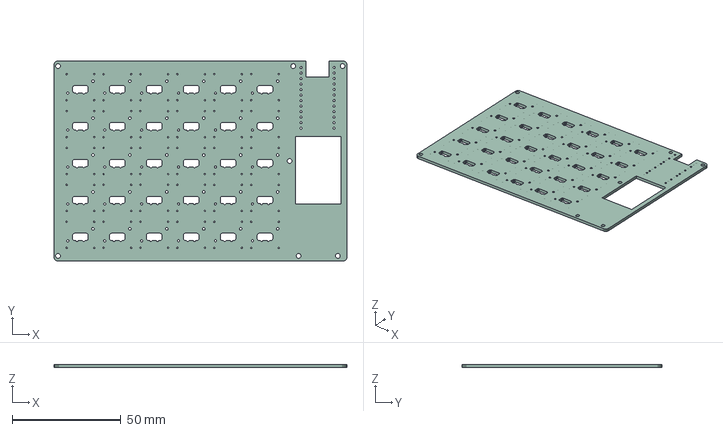
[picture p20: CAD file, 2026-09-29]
hardware/pcb/fab/left/bayleaf-left-pcb.step
134.9 x 92.3 x 1.60 mm

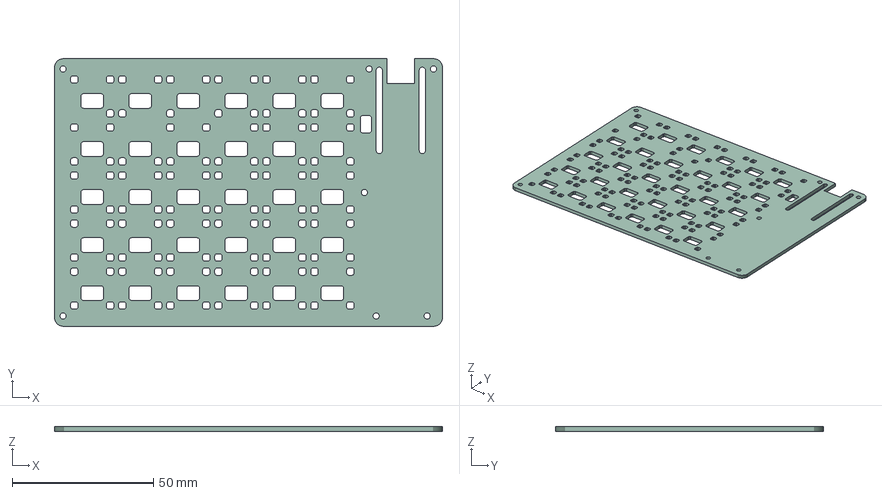
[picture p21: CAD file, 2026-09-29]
hardware/pcb/fab/plate-left/bayleaf-plate-left.step
137.3 x 94.7 x 1.60 mm

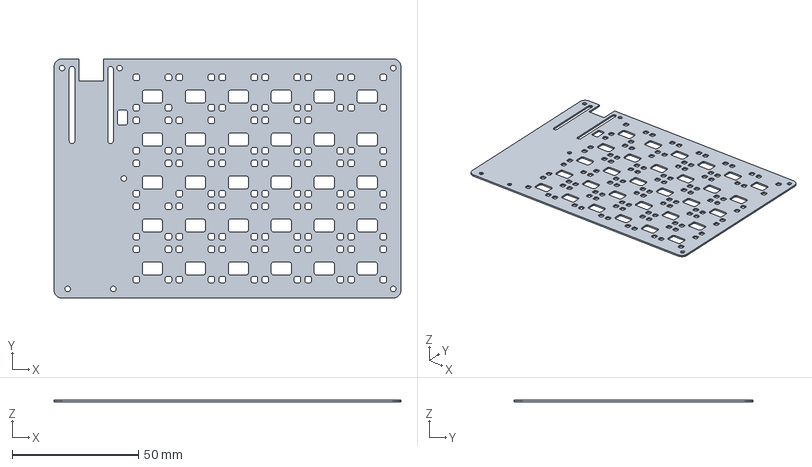
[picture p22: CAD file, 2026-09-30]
hardware/case/out/bayleaf-plate-right.step
137.3 x 94.7 x 0.8 mm

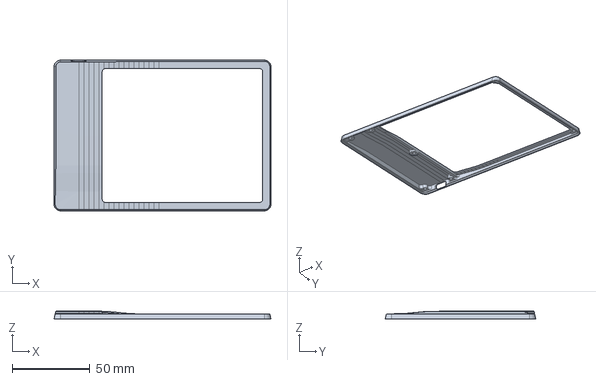
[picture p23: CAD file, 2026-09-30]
hardware/case/out/bayleaf-shell-right.step
139.4 x 96.8 x 5.00 mm

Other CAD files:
hardware/pcb/fab/plate-right/bayleaf-plate-right.step
hardware/pcb/fab/right/bayleaf-right-pcb.step
hardware/case/out/bayleaf-shell-right-corner2.step
hardware/case/out/bayleaf-shell-right-chamfer.step
hardware/case/out/bayleaf-plate-left.step
hardware/case/out/bayleaf-shell-left.step
hardware/case/out/bayleaf-shell-right-corner.step
hardware/case/out/bayleaf-shell-left-chamfer.step
hardware/case/out/bayleaf-shell-left-corner.step
hardware/case/out/bayleaf-shell-left-round.stl
hardware/case/out/bayleaf-shell-right-round.stl
hardware/case/out/bayleaf-plate-left.stl
hardware/case/out/bayleaf-plate-right.stl
hardware/case/out/bayleaf-shell-left-chamfer.stl
hardware/case/out/bayleaf-shell-left-corner.stl
hardware/case/out/bayleaf-shell-left-corner2.stl
hardware/case/out/bayleaf-shell-left.stl
hardware/case/out/bayleaf-shell-right-chamfer.stl
hardware/case/out/bayleaf-shell-right-corner.stl
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

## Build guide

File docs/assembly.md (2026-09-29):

# Assembly

Do these steps once per half. They're written for the left half; the right half is the mirror image. Plan on 2–3 hours per half if you place the diodes by hand.

**Tools:** a soldering iron with a fine tip and a small chisel tip; optionally a small hotplate for the switch anchors. No reflow oven needed. Also: thin solder wire, tweezers, flux, low-temp paste (Sn42Bi58), Kapton tape, flush cutters, multimeter.

## Stack-up

```
5.0 mm ┬ plateau over the controller: the tallest point (roof underside 4.2 mm)
~4.4   │ keycap tops
~4.0   │ top of the nice!nano; 3.0 mm LiPo on the bottom plate in front of it
3.2 mm ┼ rim around the keys and along the front; S-bends join it to the plateau
1.6 mm ┼ PCB top: the shell's posts press down here
0.8 mm ┼ PCB (0.8 mm FR4, castellated half-holes under each switch; reset button on its underside)
0.0 mm ┴ bottom plate (0.8 mm FR4, no copper), flush in the shell's rabbet; 7 thin-head M2 screws come up through it
-1.1   │ reset button, standing in a window of the plate (the 1.5 mm feet keep it off the desk)
```

## 1. Diodes (skip if JLC assembled them)

1. Put a tiny dot of paste on each SOD-523 pad pair. They sit in the narrow gap on the left of every key; on the right half, on the right.
2. Place the 1N4148WT diodes with the **cathode band on the pad marked by the silkscreen bar**. That side goes to the row trace.
3. Reflow on the hotplate section by section, or use the iron.

## 2. Switches

The whole switch can be soldered from below with an iron:

* The two **contacts** sit over plated half-holes on the edge of a window in the board. This is the hand-solder trick from Mike Holscher's [mikecinq](https://github.com/mikeholscher/zmk-config-mikecinq).
* The four **frame anchors** each have a 0.7 mm plated hole through their 2 × 2 mm pad, with a 1.4 mm pad on the bottom. Heat from below travels up the hole into the anchor. This part is new and not proven yet, so try one switch first and check it holds before doing the rest.

A hotplate still works for the anchors if you have one (step 1b).

1. **Frames, iron only (1a):**
   1. Put a small blob of low-temp paste (Sn42Bi58) on each of the four square frame pads. Put no paste on the round contact pads.
   2. Drop the PG1316S in, keycaps **off**, with the two locating pins in the two small holes.
   3. Hold the switch flat with a strip of Kapton tape across it, or a small weight.
   4. Turn the board over. On each anchor's bottom pad, hold a clean, fluxed chisel tip (about 280 °C) until the paste on top melts, 2–3 s. The joint is right when a little solder shows in the hole. If it doesn't, feed a touch of solder wire into the hole.
   5. Do the diagonal corners first so the switch can't rock.
2. **Frames, hotplate (1b):** same paste. Set that spot of the board on the hotplate, about 170 °C for Sn42Bi58, and press the switch gently while the paste is molten. The anchor holes wick a little paste down; that's fine.
3. **Contacts (iron):** turn the board over. In each window you see the switch's two contact legs next to the half-holes. Add flux and flow a little solder wire from the half-hole onto the leg: one short touch (≤ 3 s, the datasheet's iron limit) per contact. Keep the joints small; the bottom plate has a window under each one.
4. With a multimeter in continuity mode, check each key: probe the column pin at the nice!nano footprint and the diode's row side, then press the key. A dead key is almost always a contact joint, and that one you can just reheat from below. To remove a switch, heat its anchors from below one at a time while levering gently.

## 3. Reset button (bottom side)

SW31, the KMR2 tact switch, goes on the **underside** of the PCB (silkscreen "RST", beside the controller). Tin one pad, place it with tweezers, solder the other three. It's pressed from below through a window in the bottom plate, so there's no pin-hole in the top of the case.

## 4. Flash and test the nice!nano *before* soldering it

1. Download the firmware from the GitHub Actions run ("Build ZMK firmware" → artifact `bayleaf-firmware`), or build it locally (see `firmware/README.md`).
2. Plug the nice!nano in. It shows up as a USB drive (`NICENANO`); if not, short RST to GND twice.
3. Copy the `settings_reset-…uf2` file, wait for the reboot, then copy the `bayleaf_left-…uf2` file (or `bayleaf_right-…` for the right half).

## 5. Solder the nice!nano flush

1. Cover the PCB area under the controller with a layer of Kapton tape, leaving the 24 holes open (poke through with a needle).
2. Lay the nice!nano on the board, components up, USB-C over the notch in the back edge of the board.
3. Push a short piece of 0.5–0.6 mm tinned wire (cut component legs work well) through each nice!nano hole into the PCB hole below. Solder it on the top, then on the bottom.
4. Cut every pin short on the bottom side. The bottom plate has a slot under each pin row, so the joints can stand up to ~0.7 mm.

## 6. Battery

1. There is no power switch: the nice!nano is live as soon as the cell is soldered, so do this step last, after flashing and testing over USB.
2. The 3.0 mm 302030 cell drops into the window in the PCB in front of the controller. It rests on the bottom plate.
3. Solder the cell's red lead to **+** and black to **−** on the BT1 pads. Keep the leads short.
4. Put Kapton on the cell. It's held by a small piece of thin double-sided tape once the plate is on.

## 7. Close the case

1. Lay the shell upside down on a soft cloth.
2. Drop the PCB in, keys down, so the switches go into the key window, and the USB-C into the opening in the back wall. The 7 holes in the PCB line up with the shell's posts.
3. Stick the battery to the bottom plate where it will meet the cell, then drop the plate into the rabbet, silkscreen out. The reset button drops into its window; the FR4 plate is an insulator, so no film is needed between it and the PCB.
4. Screw in the thin-head screws: M2×2 in the four posts under the rim (both key-frame corners and the front pair at the bay; their threads are only 1.1 mm deep), M2×3 in the other three (back of the bay, divider). Snug, not tight: the posts clamp the PCB.
5. Snap on the 30 keycaps and stick 4 bumpons under each half.

## 8. Pair

1. Both halves start as soon as their cells are connected. They pair with each other automatically; the left half is the BLE "central".
2. On the computer, pair with **Bayleaf**. The reset button is on the underside, in the window of the bottom plate. Lower+Raise gives the Adjust layer, which has the BT profile keys, `BT_CLR`, and `&bootloader` for later firmware updates over USB.

## Troubleshooting

* **A key doesn't register:** usually a switch contact pad that didn't wet. Reflow that switch, or touch up its pads from the side with the iron.
* **A whole row or column is dead:** check the flush joints on the nice!nano pins.
* **The halves don't connect:** flash `settings_reset` to both halves, then the real firmware again.
* **Short range in the aluminium case:** the controller sits under the aluminium roof, so the radio gets out downward through the FR4 bottom plate (keep it copper-free) and through the key window. The firmware already sets TX power to +8 dBm. Don't put the keyboard on a metal desk or laptop palm rest. If range is still poor, a printed (MJF/SLS) shell avoids the problem.

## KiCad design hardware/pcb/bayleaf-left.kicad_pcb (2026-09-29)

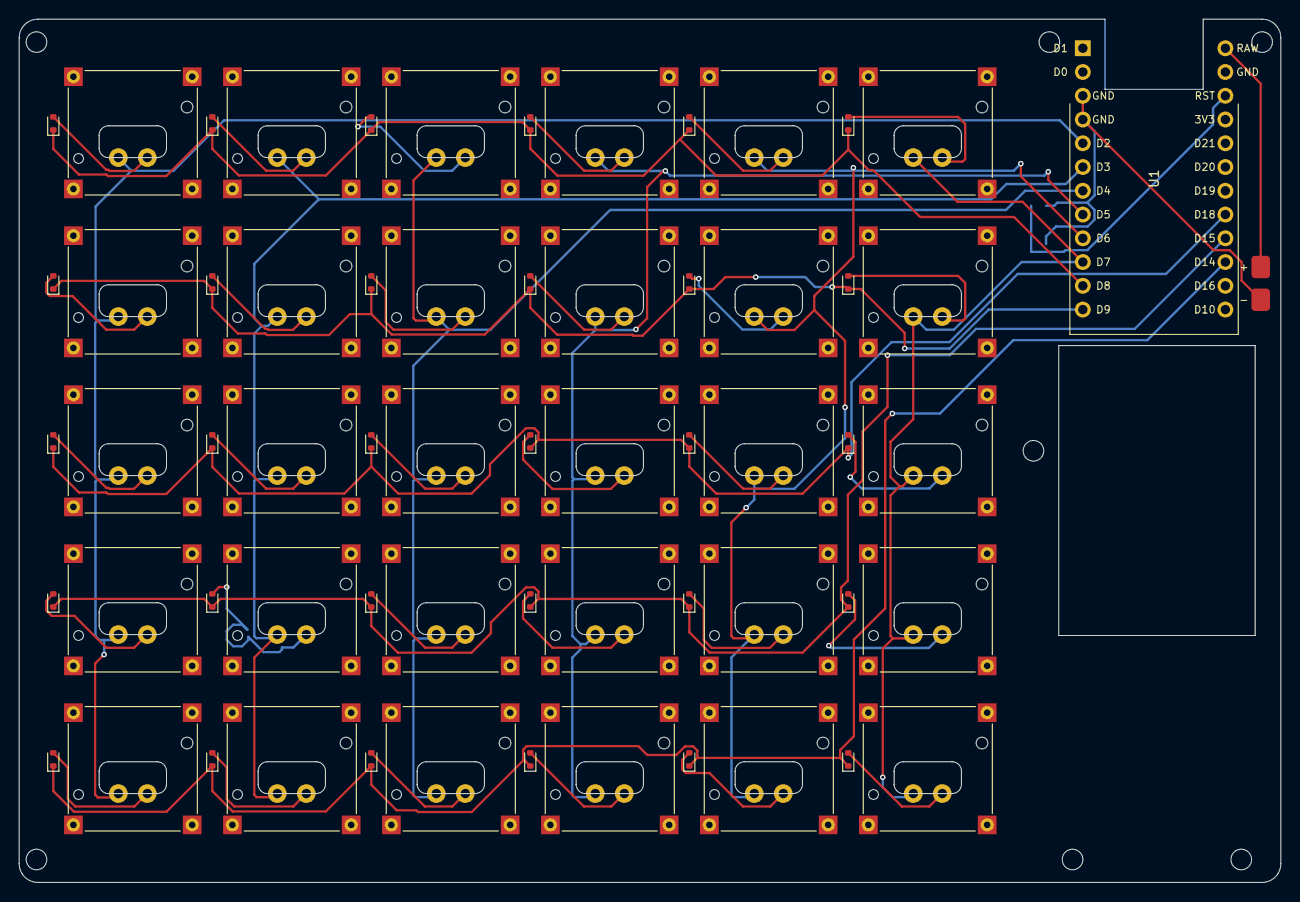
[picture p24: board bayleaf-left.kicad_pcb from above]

Board: 2 copper layers, 134.9 x 92.3 mm, 70 parts (1 on the bottom side), 44 nets.

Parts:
BT1: LiPo 3.7V; Battery_Pads_Small
D1, D2, D3, D4, D5, D6, D7, D8, D9, D10, D11, D12, D13, D14, D15, D16, D17, D18, D19, D20, D21, D22, D23, D24, D25, D26, D27, D28, D29, D30: 1N4148WT; D_SOD-523
H1, H2, H5, H6, H7: boss 6; MountingHole_2.2mm_M2
H3, H4: boss 4; MountingHole_2.2mm_M2
SW1, SW2, SW3, SW4, SW5, SW6, SW7, SW8, SW9, SW10, SW11, SW12, SW13, SW14, SW15, SW16, SW17, SW18, SW19, SW20, SW21, SW22, SW23, SW24, SW25, SW26, SW27, SW28, SW29, SW30: PG1316S; Kailh_PG1316S_castellated
SW31: KMR211NGLFS; SW_Push_1P1T_NO_CK_KMR2
U1: nice!nano v2; nice_nano_v2_flush

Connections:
COL0: SW1.1, SW7.1, SW13.1, SW19.1, SW25.1, U1.5
COL1: SW2.1, SW8.1, SW14.1, SW20.1, SW26.1, U1.6
COL2: SW3.1, SW9.1, SW15.1, SW21.1, SW27.1, U1.7
COL3: SW4.1, SW10.1, SW16.1, SW22.1, SW28.1, U1.8
COL4: SW5.1, SW11.1, SW17.1, SW23.1, SW29.1, U1.9
COL5: SW6.1, SW12.1, SW18.1, SW24.1, SW30.1, U1.10
GND: BT1.2, SW31.2, U1.3, U1.4
N_SW1: D1.2, SW1.2
N_SW2: D2.2, SW2.2
N_SW3: D3.2, SW3.2
N_SW4: D4.2, SW4.2
N_SW5: D5.2, SW5.2
N_SW6: D6.2, SW6.2
N_SW7: D7.2, SW7.2
N_SW8: D8.2, SW8.2
N_SW9: D9.2, SW9.2
N_SW10: D10.2, SW10.2
N_SW11: D11.2, SW11.2
N_SW12: D12.2, SW12.2
N_SW13: D13.2, SW13.2
N_SW14: D14.2, SW14.2
N_SW15: D15.2, SW15.2
N_SW16: D16.2, SW16.2
N_SW17: D17.2, SW17.2
N_SW18: D18.2, SW18.2
N_SW19: D19.2, SW19.2
N_SW20: D20.2, SW20.2
N_SW21: D21.2, SW21.2
N_SW22: D22.2, SW22.2
N_SW23: D23.2, SW23.2
N_SW24: D24.2, SW24.2
N_SW25: D25.2, SW25.2
N_SW26: D26.2, SW26.2
N_SW27: D27.2, SW27.2
N_SW28: D28.2, SW28.2
N_SW29: D29.2, SW29.2
N_SW30: D30.2, SW30.2
RAW: BT1.1, U1.13
ROW0: D1.1, D2.1, D3.1, D4.1, D5.1, D6.1, U1.11
ROW1: D7.1, D8.1, D9.1, D10.1, D11.1, D12.1, U1.12
ROW2: D13.1, D14.1, D15.1, D16.1, D17.1, D18.1, U1.20
ROW3: D19.1, D20.1, D21.1, D22.1, D23.1, D24.1, U1.21
ROW4: D25.1, D26.1, D27.1, D28.1, D29.1, D30.1, U1.22
RST: SW31.1, U1.15

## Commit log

2026-09-28 Add Bayleaf keyboard reproduction: PCB, case, firmware, BOM
    Independent re-creation of the Bayleaf ultra-low-profile wireless split
    keyboard (2 x 5x6 ortho, Kailh PG1316S, nice!nano, ZMK, 139 x 93 x 5 mm
    CNC aluminium case), designed from the published specs.
    - hardware/pcb: PCBs generated by a KiCad 7 python script, autorouted
    with Freerouting, DRC-clean; gerbers, drill, JLC BOM/CPL, STEP
    - hardware/case: parametric CadQuery case, STEP/STL for CNC and MJF
    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
    [BOM.csv, bayleaf-case-left-mjf.step, bayleaf-case-left-mjf.stl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]
2026-09-28 docs: add 3D renders (three.js) and electronics-only cost
    Renders use the real case STEP/STL and a PCB texture composited from the
    routed KiCad boards; docs/render3d/render.sh regenerates them.
    Claude-Session: https://claude.ai/code/session_01C1HRLCKaYQawWFomwAvAgT
    [BOM.csv]
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2026-09-28 Case: rebuild after the original's MK5 drawing (shell + lid over controller)
    - hardware/case: top shell with 103 x 86 key window, 2 mm divider, 27 mm
    controller bay closed by a 0.8 mm roof, 6.2 -> 3.8 mm front curve, drafted
    walls, 7 tapped M2 bosses; separate 0.8 mm bottom plate screwed into them
    - PCB: 17 mm pitch to fit the window, SOD-523 diodes, nice!nano rotated so
    USB-C exits the front, 402040 cell under the roof, 2.2 mm holes + copper
    keep-outs at the bosses, per-half matrix pin map; both halves route clean
    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
    [BOM.csv, bayleaf-case-left-mjf.step, bayleaf-case-left-mjf.stl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]
2026-09-28 Case: match the build photos - 5 mm tall, separate controller lid
    - shell: 3.8 mm frame around the key window curving up to 4.1 mm at the
    controller end; controller bay now open on top; all posts M2 x 2
    - new lid part: 0.8 mm plate over the bay, flush with the outer edges, taped
    on; its top is the 5.0 mm tallest point (contrast anodised like the original)
    - 302040 cell (bay under the lid is 3.4 mm), 14 x M2x3 screws
    - renders: silver shell, blue lid, blank caps; desk/front views like the photos
    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
    [BOM.csv, bayleaf-left.kicad_pcb, bayleaf-lid-left.step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]
2026-09-28 Case: reproduce the soft bends of the original shell
    - top surface is now a blend of two smooth S-curves: the frame dips from
    4.1 mm at the back to 3.1 mm along the front edge (drawing side views), and
    that dip fades out toward the controller so the front face rises to the lid
    (section A / build photos); 0.5 mm round on the outer top edge
    - thread depth per post from the local surface height (front-left 1.1 mm,
    M2x2 screw); docs, BOM and renders (new end view) updated
    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
    [BOM.csv, bayleaf-lid-left.step, bayleaf-lid-right.step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]
2026-09-29 Case: one-piece shell from the sketchpad shape (3.2 mm rim, 5.0 mm plateau, S-bends)
    - case.py: top surface = blurred square plateau (x >= 96.5, y <= 76) over a 3.2 mm rim;
    controller roofed by the shell (no lid), R2 key-window corners, USB-C in the back wall,
    reset pin-hole, per-post thread depths (2 mm / 1.1 mm)
    - PCB: nice!nano USB-C facing the back, KMR2 reset and slide switch beside it, 302030 cell
    window in front of it; rerouted, fab outputs regenerated
    - firmware: per-half matrix pins to match the new layout
    - docs: sketchpad shape saved, renders, BOM/ordering/assembly/case/schematic updated
    Claude-Session: https://claude.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
    [BOM.csv, bayleaf-left-jlc-bom.csv, bayleaf-left-pcb.step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]
2026-09-29 Drop the power switch, stadium USB-C opening, straight-wall + chamfer case variant
    - PCB: no slide switch; the cell feeds the nice!nano RAW pin directly (ZMK deep sleep);
    rerouted, 0 unconnected, courtyard warning gone
    - case: obround USB-C opening concentric with the receptacle (continues into the plate
    edge), no switch slot; new bayleaf-shell-*-chamfer variant with vertical walls and a
    1 mm 45 deg chamfer on the top edge that follows the blended surface
    - renders: obround receptacle, compare.jpg (drafted vs chamfer); docs and BOM updated
    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
    [BOM.csv, bayleaf-left-jlc-bom.csv, bayleaf-left-pcb.step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]
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2026-09-29 Case: round every inside corner of the underside pocket to R1.65 for CNC (SendCutSend-ready STEP)
    The underside is hollowed in three layers (under the PCB plane, around the posts, around the
    posts + divider); each layer's outline is a morphological opening for a 3.3 mm cutter, so
    post/wall/divider junctions get R1.65 fillets and sub-tool gaps stay solid. Single solid per
    STEP, mm, threads as tap drills. Ordering notes for SendCutSend.
    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
    [bayleaf-plate-left.step, bayleaf-plate-right.step, bayleaf-shell-left-chamfer.step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]
2026-09-29 Hand-solderable switches, FR4 bottom plate, reset button on the underside
    - PCB: new Kailh_PG1316S_castellated footprint (window under each switch, contacts on plated
    half-holes, soldered from below with an iron; frame anchors on a small hotplate), after
    Mike Holscher's mikecinq, drawn from the Kailh land pattern. Order with castellated holes.
    Routing gets notched keepouts so Freerouting can reach the half-hole pads.
    - Reset (KMR2) moves to the bottom side; the pin-hole in the plateau is gone.
    - Bottom plate is now a copper-free 0.8 mm FR4 board (generate_pcb.py PlateBuilder, gerbers
    in fab/plate-*) so the radio isn't boxed in by aluminium; windows for the switch solder,
    nice!nano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
    [BOM.csv, bayleaf-left-jlc-bom.csv, bayleaf-left-pcb.step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]
2026-09-29 Switch frame anchors solderable from below: plated holes in the anchor pads
    - Kailh_PG1316S_castellated: each 2x2 mm frame-anchor pad gets a 0.7 mm plated hole with a
    1.4 mm pad on the bottom, so the whole switch can be soldered from the underside with an
    iron (hotplate still works). Switch window narrowed to 7.2 mm to keep routing channels.
    - Bottom plates: 2.6 mm windows under every anchor hole; silkscreen moved under the battery.
    - Router: plain notches again (the 0.3 mm margin choked Freerouting); every attempt is now
    rejected if it leaves copper on a window edge.
    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
    [BOM.csv, bayleaf-left-pcb.step, bayleaf-left.kicad_pcb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]
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
